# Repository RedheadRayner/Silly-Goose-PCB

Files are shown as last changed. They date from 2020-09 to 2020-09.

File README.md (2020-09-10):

# Silly Goose

Silly Goose is the name of the first version of my handheld gaming PCB. I created this with the intention of having my own portable tetris gaming device. I am a great fan of tetris and was disappointed that most portable devices did not have the correct tetris rules or failed to save scores when powered off (so I took matters into my own hands!).

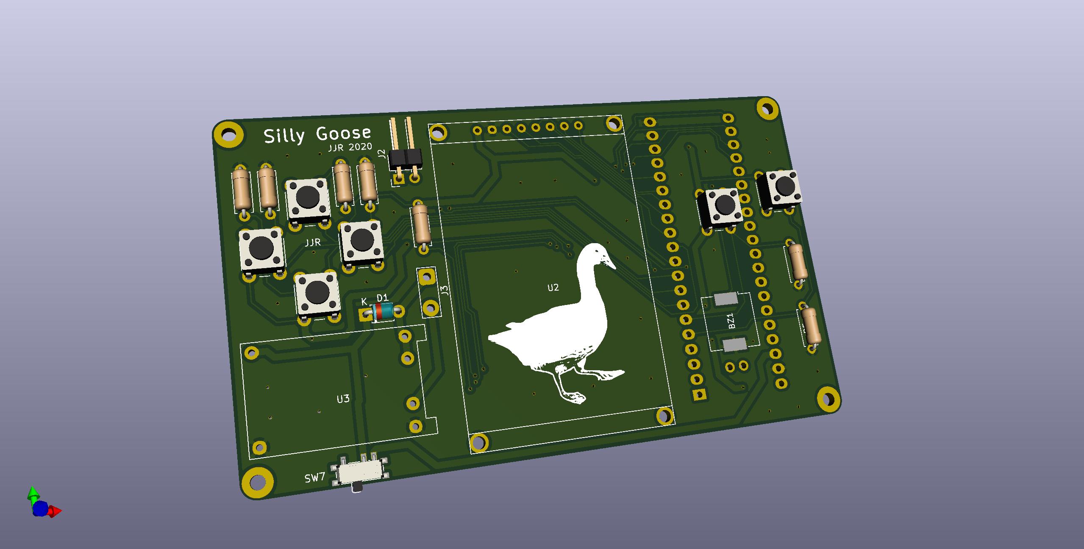
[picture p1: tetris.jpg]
Silly Goose PCB image


## Games

Currently, the following games are created:
- [Tetris](https://github.com/RedheadRayner/Tetris)

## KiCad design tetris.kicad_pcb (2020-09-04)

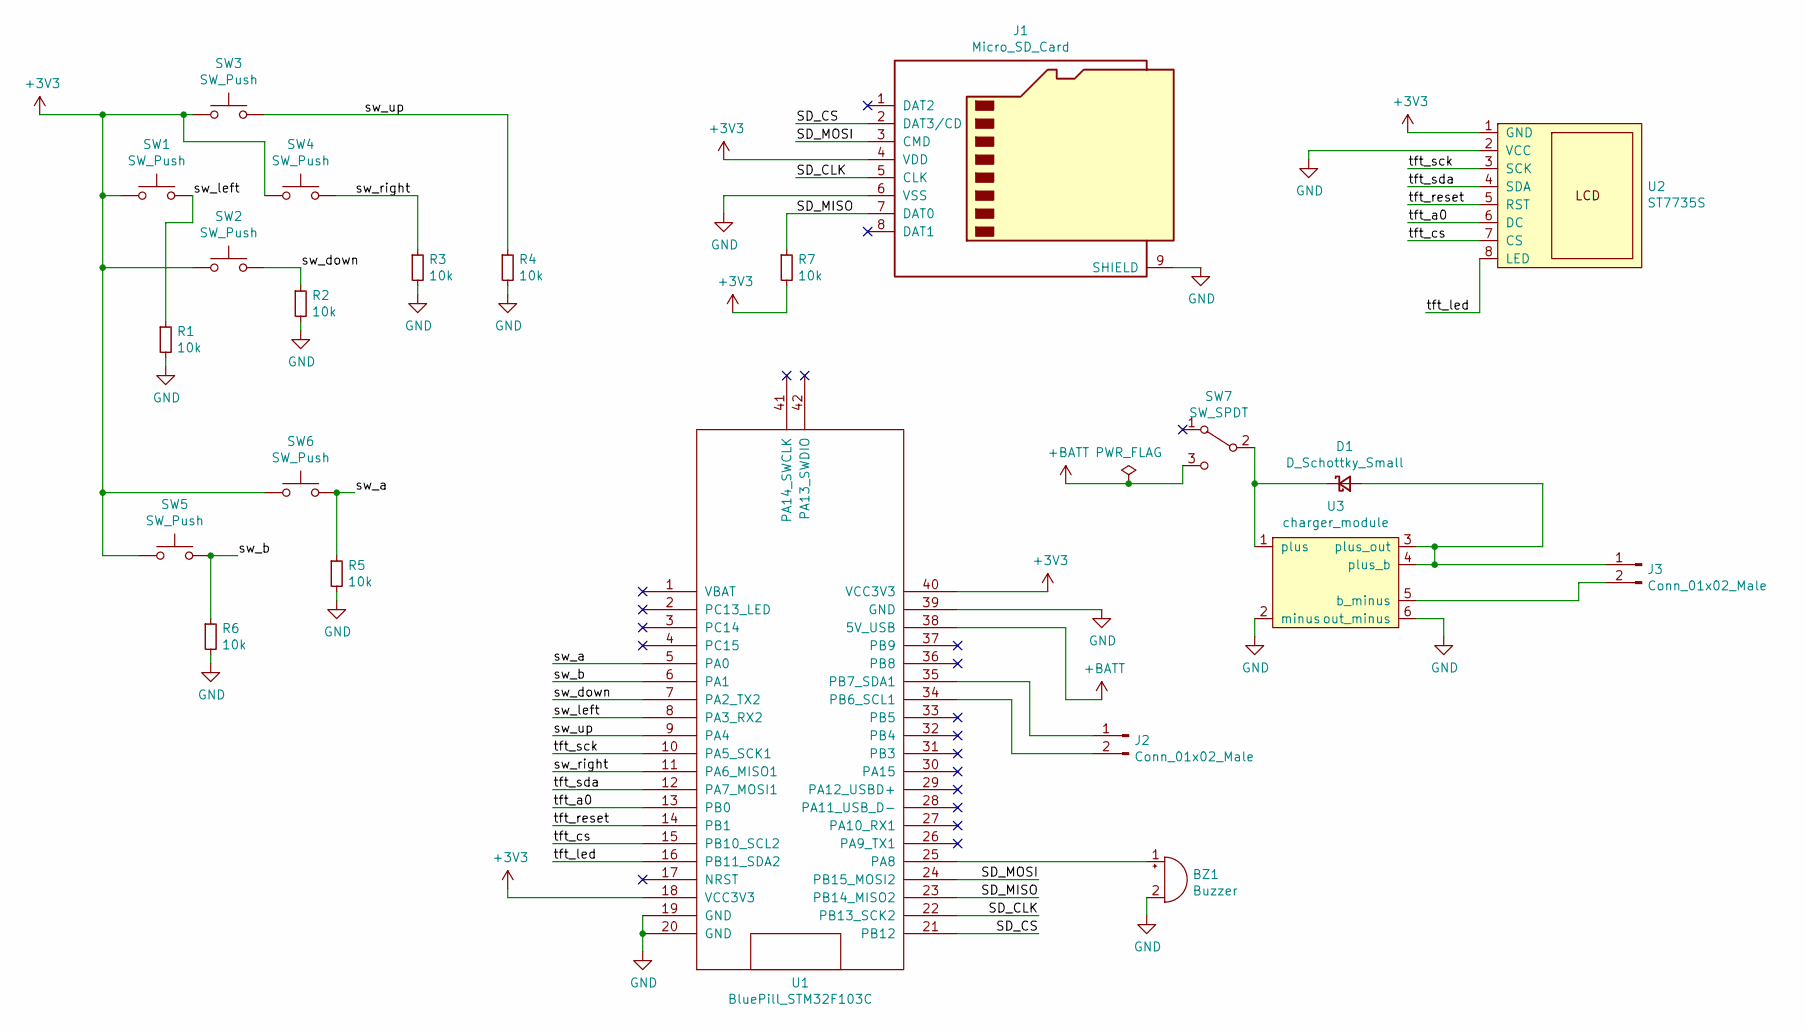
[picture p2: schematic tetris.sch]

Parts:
BZ1: Buzzer; Buzzer_CUI_CPT-9019S-SMT
D1: D_Schottky_Small; D_T-1_P5.08mm_Horizontal
J1: Micro_SD_Card; microSD_HC_Hirose_DM3AT-SF-PEJM5
J2: Conn_01x02_Male; PinHeader_1x02_P2.54mm_Horizontal
J3: Conn_01x02_Male; TestPoint_2Pads_Pitch5.08mm_Drill1.3mm
R1, R2, R3, R4, R5, R6, R7: 10k; R_Axial_DIN0207_L6.3mm_D2.5mm_P7.62mm_Horizontal
SW1, SW2, SW3, SW4, SW5, SW6: SW_Push; SW_PUSH_6mm
SW7: SW_SPDT; SW_SPDT_PCM12
U1: BluePill_STM32F103C
U2: ST7735S; st7735s
U3: charger_module

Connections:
+3V3: J1.4 (VDD), R7.2, SW1.1, SW2.1, SW3.1, SW4.1, SW5.1, SW6.1, U1.18 (VCC3V3), U1.40 (VCC3V3), U2.1 (GND)
+BATT: SW7.3 (C), U1.38 (5V_USB)
/SD_CLK: J1.5 (CLK), U1.22 (PB13_SCK2)
/SD_CS: J1.2 (DAT3/CD), U1.21 (PB12)
/SD_MISO: J1.7 (DAT0), R7.1, U1.23 (PB14_MISO2)
/SD_MOSI: J1.3 (CMD), U1.24 (PB15_MOSI2)
/sw_a: R5.1, SW6.2, U1.5 (PA0)
/sw_b: R6.1, SW5.2, U1.6 (PA1)
/sw_down: R2.1, SW2.2, U1.7 (PA2_TX2)
/sw_left: R1.1, SW1.2, U1.8 (PA3_RX2)
/sw_right: R3.1, SW4.2, U1.11 (PA6_MISO1)
/sw_up: R4.1, SW3.2, U1.9 (PA4)
/tft_a0: U1.13 (PB0), U2.6 (DC)
/tft_cs: U1.15 (PB10_SCL2), U2.7 (CS)
/tft_led: U1.16 (PB11_SDA2), U2.8 (LED)
/tft_reset: U1.14 (PB1), U2.5 (RST)
/tft_sck: U1.10 (PA5_SCK1), U2.3 (SCK)
/tft_sda: U1.12 (PA7_MOSI1), U2.4 (SDA)
GND: BZ1.2 (+), J1.6 (VSS), J1.9 (SHIELD), R1.2, R2.2, R3.2, R4.2, R5.2, R6.2, U1.19 (GND), U1.20 (GND), U1.39 (GND), U2.2 (VCC), U3.2 (minus), U3.6 (out_minus)
unnamed: BZ1.1 (-), U1.25 (PA8)
unnamed: D1.1 (K), SW7.2 (B), U3.1 (plus)
unnamed: D1.2 (A), J3.1, U3.3 (plus_out), U3.4 (plus_b)
unnamed: J2.1, U1.35 (PB7_SDA1)
unnamed: J2.2, U1.34 (PB6_SCL1)
unnamed: J3.2, U3.5 (b_minus)

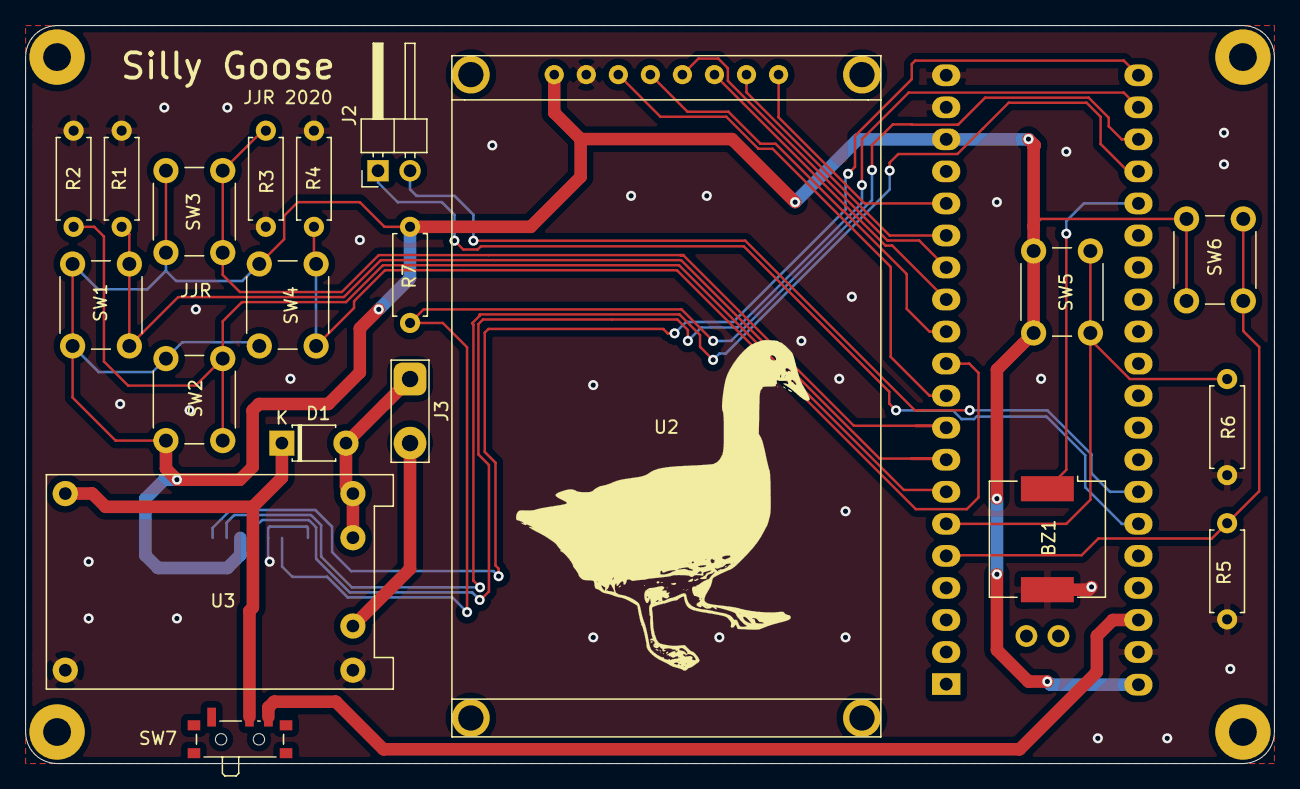
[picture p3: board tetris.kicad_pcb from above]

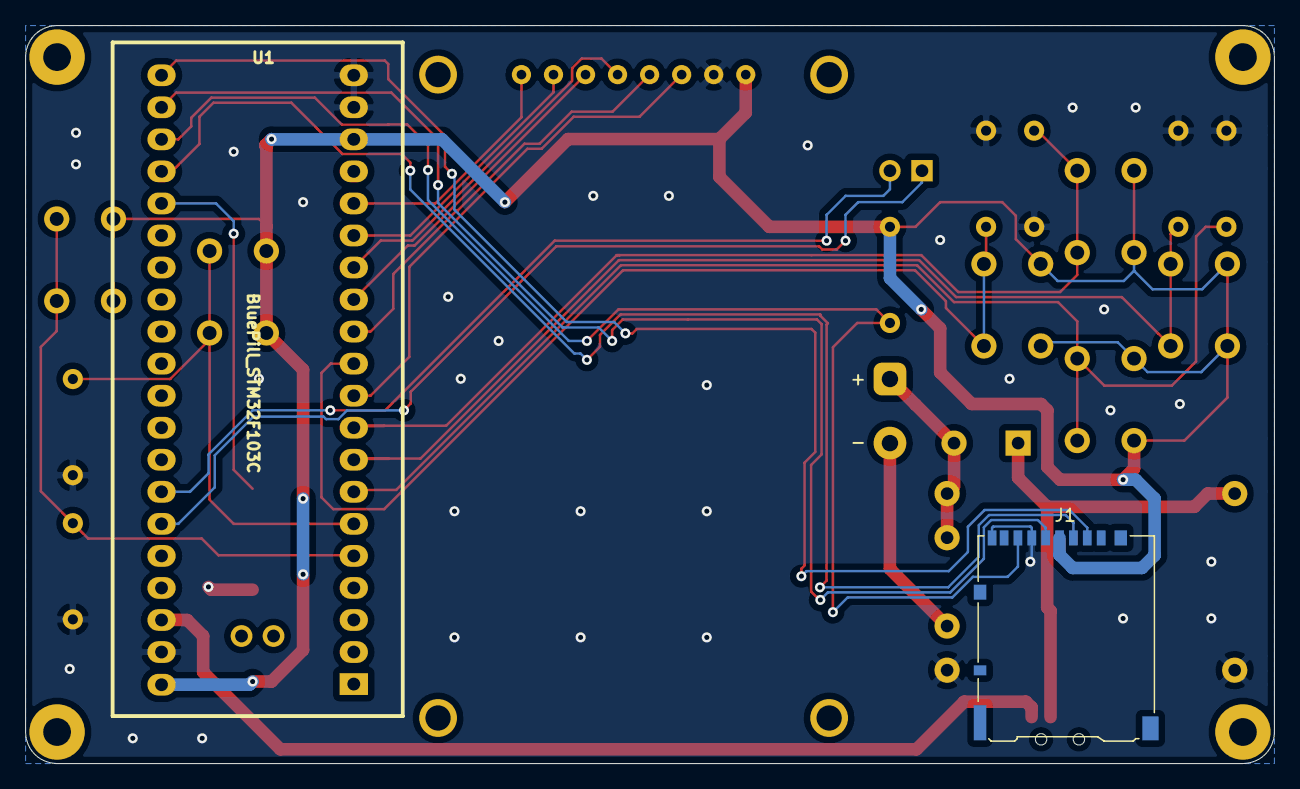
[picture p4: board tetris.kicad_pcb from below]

Board: 2 copper layers, 99.0 x 58.5 mm, 26 parts (2 on the bottom side), 25 nets.

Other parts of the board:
 : MountingHole_2.2mm_M2_Pad
 #2,  #3,  #4: MountingHole_2.2mm_M2_Pad
